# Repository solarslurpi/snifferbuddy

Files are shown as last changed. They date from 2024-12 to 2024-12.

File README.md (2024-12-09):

(snifferbuddy_doc)=
# SnifferBuddy
## About
SnifferBuddy, a puck-shaped device, measures ambient conditions—temperature, humidity, CO2, and light status—in the grow tent using an SCD4x sensor and a photoresistor. It calculates VPD and publishes the data via MQTT.

This guide details the process of assembling SnifferBuddy, configuring its software, and understanding its operation.  

SnifferBuddy broadcasts MQTT messages packed with SCD-4x sensor data. Node-red, home assistant, and any software tuned to SnifferBuddy's MQTT topic can pick up and utilize this data. 

## Glossary
- **MQTT (Message Queuing Telemetry Transport)**: A lightweight messaging protocol used for sending and receiving telemetry data in the form of messages between devices, servers, and applications. MQTT is especially useful in scenarios where network bandwidth is at a premium.
- **SCD-4x**: This refers to a series of CO2 sensors from Sensirion, specifically the SCD-40 and SCD-41 models. These sensors are integrated into breakout boards developed and sold by Adafruit. The breakout boards make it easier to interface with and use the sensors in projects. The Adafruit product pages for the [SCD-40](https://www.adafruit.com/product/5187) and [SCD-41](https://www.adafruit.com/product/5190) provide further details. SnifferBuddy uses this breakout board.
- **STEMMA Connector**: STEMMA is a standard adopted by Adafruit to make connecting sensors and devices easier, eliminating the need for soldering. It uses JST connectors, specifically JST PH for larger, power-focused connections and JST SH for smaller, data-focused connections. STEMMA connectors means connections don't require soldering or breadboarding {material-regular}`celebration;1em;sd-text-blue`.
- **QT Py ESP32-S2**: Adafruit's compact microcontroller, featuring an ESP32-S2 chip with built-in USB and Wi-Fi capabilities. It supports easy, solder-free connections to devices via a built-in STEMMA QT connector. More on [the product page](https://www.adafruit.com/product/5187).
- **CircuitPython**: An open-source derivative of MicroPython developed and maintained by Adafruit. The design intent is to simplify experimenting and learning to code on low-cost microcontroller boards. More on [the product page](https://circuitpython.org/)
(make_snifferbuddy)=
## Make SnifferBuddy
### 1. Get the parts together

The hardware needed to build SnifferBuddy includes:

| Component | Cost | Reason |
|---|---|---|
| [QT Py ESP32-S2](https://www.adafruit.com/product/5325) | $12.50 | Excellent quality.  Easy to use with CircuitPython and WiFi. STEMMA connector makes it easy to connect the SCD-40 or 41.  Small size.
| [USB-C DATA Cable](https://amzn.to/3OW5SdE) | $10 | Includes wires for data transfer.  There are probably more inexpensive cables.  Please make sure to use one with data wires.
| [SCD-40 BoB](https://www.adafruit.com/product/5187) | $44.95 | Excellent quality.  Provides accurate CO2 readings.  STEMMA connector makes it easy to connect to the QT PY.
| [JST SH 4-Pin Cable](https://www.adafruit.com/product/4399) | $0.95 | Excellent quality. Connects the QT PY to the SCD-4x. No soldering required.
| Photoresistor | pennies | At some point I bought [a pack of photoresistors on Amazon](https://www.amazon.com/s?k=photoresistor).
| 12K  Resistor | pennies | As with photoresistors, I bought [a pack of resistors on Amazon](https://www.amazon.com/s?k=resistor).
| wiring | pennies | I like to use [silicone wires like this wire kit on Amazon](https://amzn.to/3C6chLU).
| enclosure | pennies | The design is an evolution of the wonderful [Tiny-D1 modular case for Wemos D1 mini by sumpfing](https://www.thingiverse.com/thing:4084654).  Thank you!

### 2. Print out the Enclosure
```{figure} images/snifferbuddy_on_printbed.jpg
:align: center
:height: 350

Top and Bottom Rings of the SnifferBuddy enclosure.
```

Print out these files on your 3D printer:
- Top Ring: Print out [scd40-ring.3mf](../enclosures/SnifferBuddy/scd-40/scd40-ring.3mf).
- Bottom Ring: Print out [bottom_qtpy.3mf](../enclosures/SnifferBuddy/scd-40/bottom_qtpy.3mf).

(_connect_wires)=
### 3. Connect Wires
- Connect the photoresistor wiring.  This requires a bit of soldering.
```{figure} images/SnifferBuddy_photoresistor_wiring.png
:align: center
:height: 350

Diagram of Photoresistor Wiring
```
```{figure} images/snifferbuddy_photoresistor_wiring_real.jpg
:align: center
:height: 350

QT Py wired with the Photoresistor circuit.
```
Use A2 as the pin to read for the photoresistor.
- Connect the QT Py and the SCD40.
```{figure} images/snifferbuddy_connected_scd4x.jpeg
:align: center
:height: 350

QT Py connected to scd4x sensor using Adafruit's STEMMA QT
```
### 4. Install CircuitPython onto the QT Py

Follow [Adafruit's instructions](https://learn.adafruit.com/adafruit-qt-py-esp32-s2/circuitpython).

```{note}
The CircuitPython version tested for compatibility with SnifferBuddy was 8.1.0.
```

### 5. Download Files To CircuitPython's Root Dir
{material-regular}`celebration;1em;sd-text-blue`  It is so wonderfully amazing that we can just drag and drop files onto our QT Py {material-regular}`celebration;1em;sd-text-blue`

Download these two files to the CIRCUITPY drive:

{material-regular}`download;1em;sd-text-success` [code.py](../growbuddiesproject/growbuddies/CircuitPython/src/code.py)
   - contains all of SnifferBuddy's code.  The code is [discussed later](_code_doc).

{material-regular}`download;1em;sd-text-success` [conf.json](../growbuddiesproject/growbuddies/CircuitPython/src/config.json)
   - contains all the values that can be changed.  The contents of the config file is discussed below.
### 6. Edit then Save the config file
The contents of the config file are listed below.  At a minimum, the wifi ssid and password must be set.

```{eval-rst}
.. literalinclude:: ../growbuddiesproject/growbuddies/CircuitPython/src/config.json

```
- **name and version**: The 'name' field distinguishes each SnifferBuddy when multiple units are used. The 'version' field indicates the code version running on each SnifferBuddy's QT Py microcontroller, ensuring accurate tracking of software updates.
- **wifi ssid and password**:  **Before deploying SnifferBuddy, it's essential to update these values** to align with your home network's WiFi settings.
- **mqtt broker and port**: Use any MQTT broker.  By default, the MQTT broker is Gus.  The default MQTT port is 1883.
- **temperature_unit**: The value is either an "F" or a "C", depending if readings should be stored in Fahrenheit or in Celsius.
- **sensor_type**: Supported types include scd40 and scd41.
- **light_threshold**: It is essential to know whether the grow light is on or off. SnifferBuddy uses the Photoresistor as a means to determine the relative light level.  As shown in the diagram within the [wiring section](_connect_wires), the light level is read from an analog pin on the QT Py.  The Photoresistor is the bottom resistor in the Voltage Divider circuit.  This means the more light, the higher the reading will be for the light level.  When code.py is run from Mu, print statements will show the light reading as shown below:

```
Published: {"scd41": {"vpd": 1.43, "temperature": 78.314, "name": "sunshine", "light": "OFF", "co2": 929, "humidity": 45.5017, "unit": "F", "version": 0.1}}
light reading: 45735
```
In this case, the reading is 45,735.  You may want to experiment to find the "ideal" threshold value for your setup.  It turned out 51000 was the ideal value for mine.
- **log_topic**: The MQTT topic used by the logging handler to send log messages to the MQTT broker.
- **lwt_topic**: Used along with **offline_payload** to set the Last Will and Testament. The **online_payload** is sent to the **lwt_topic** upon receiving a callback from the MQTT Broker that SnifferBuddy has connected.
```
    mqtt_client.will_set(config["lwt_topic"], config["offline_payload"], retain=True)
```
- **payload_topic**: The topic used to send the light info and scd4x readings.
### 7. Download Library Files to the lib Directory
Create the lib directory on your CIRCUITPY drive.
#### a. Download to the CIRCUITPY/lib directory:
{material-regular}`download;1em;sd-text-success` [log_mqtt.py](../growbuddiesproject/growbuddies/CircuitPython/src/log_mqtt.py)
#### b. Download the CircuitPython Libraries
Based on the version of CircuitPython you installed on the QT Py, download the [corresponding CircuitPython Libraries](https://circuitpython.org/libraries).
#### c. Copy Libraries to the CIRCUITPY/lib directory:
The following libraries need to be copied to CIRCUITPY/lib:
- adafruit_minimqtt
- adafruit_logging.mpy
- adafruit_scd4x.mpy
### 8. Plug In Your SnifferBuddy
At this point, we're hoping everything "just works"!  Plug in your SnifferBuddy to a 5V USB port.  If SnifferBuddy is working, there will be entries in the MQTT broker.
## Accuracy - SCD4x
Section 1 of the [SCD4x datasheet](https://sensirion.com/media/documents/48C4B7FB/6426E14D/CD_DS_SCD40_SCD41_Datasheet_D1_052023.pdf) describes the lower and upper bounds that a CO2, relative humidity, or temperature reading will range based on the SCD4x's accuracy.  A python program, `calculate_scd40_bounds.py`, calculates these offsets given a value for the SCD40.  For example, if the temperature reads 70 degrees F, the actual value can range from 68.6 to 71.4 degrees based on the accuracy.

## Adjusting Temperature and Relative Humidity Readings - SCD4x

### On-Chip Signal Compensation
A temperature offset is utilized to fine-tune the sensor's temperature and relative humidity (RH) output signals. The correlation between temperature and humidity necessitates an accurate temperature reading for a precise RH reading, given that moisture-carrying capacity of air is temperature-dependent. The [SCD4x datasheet](https://sensirion.com/media/documents/48C4B7FB/6426E14D/CD_DS_SCD40_SCD41_Datasheet_D1_052023.pdf) discusses the On-Chip Output Signal Compensation in section 3.6.  It's the way the chip compensates for temperature readings skewed due to self-heating from the sensor and nearby electronics, while also taking into account other influences like ambient temperature variations and airflow disruptions.   Initially, the temperature offset is set to 4°C to mitigate self-generated heat, with adjustable values between 0°C and 20°C to accommodate other environmental factors. Although a negative offset could technically be used if the sensor reads too cold, it's outside the recommended range.
### Adjusting temperature readings
1. Determine if a temperature offset is needed by placing an external reference temperature sensor with snifferbuddy and determine if after 24 hours.
2. If the reading is significantly outside the bounds, consider changing the temperature offset.
3. Place the SnifferBuddy and a reference temperature sensor at the place in the grow tent you wish to have SnifferBuddy hanging around. Wait 24 hours so both sensor aclimate.
## Adjusting Light ON/OFF threshold
A simple photoresistor is used to determine whether the light is on or off. CircuitPython maps photoresistor readings to values between 0 and 65535.  By default, light on happens when the photoresistor value is > 45,000.  This can be adjusted.
1. Put SnifferBuddy where you want to hang it.
2. Turn the light on. If SnifferBuddy sends readings that says the light is on, you are done.
3. If SnifferBuddy says the light is off when it is on, send a calibrate light mqtt message.  By doing so, SnifferBuddy will adjust it's light threshold.

## Debug
Sadly, it is a rare moment when something works the first time. Take a deep breath and let's get started!
### Check the Print Statements
In this scenario, the QT Py is plugged into a USB on your PC/Mac.  You have installed the [Mu editor](https://codewith.mu/), and can load and run code.py.  There are print statements that should help you determine what the problem might be.
### Check Out the MQTT Broker
Have any messages been sent?  The easiest way to check is to use a tool like [mqtt Explorer](http://mqtt-explorer.com/).  This tool does exactly what the name implies.  It allows you to explore the mqtt traffic as it whizzes by.  You can also publish messages.  Very handy.
```{figure} images/mqtt_explorer.jpg
:align: center
:height: 350

SnifferBuddy Topics on the Gus MQTT Broker
```
The first messages sent include:
1. A message to the lwt topic letting everyone know a SnifferBuddy is connected to the MQTT broker.

```
    client.publish(userdata["lwt_topic"], userdata["online_payload"], retain=True)
```
Check the configuration file for what the actual "online_payload" message is.

2. A log message sent before readings are published.

```
logger.debug("Sending Readings")
```
The logging message with be under the config['log_topic'] (default is SnifferBuddy/log).  It will look like this:
```
8.000: DEBUG - Sending Readings
```
Where:
- 8.000 is a floating point number that represents the number of seconds since boot (see [monotonic time](https://learn.adafruit.com/clue-sensor-plotter-circuitpython/time-in-circuitpython )).
- DEBUG notes this logging message to be at the debug level.
- "Sending Readings" is the message.

### Using LWT and Logging for Debugging

SnifferBuddy has set up the optional Last Will and Testament (LWT) feature of MQTT. LWT is a method to notify clients by the broker when the client ungracefully disconnects or stops sending messages.  To set up LWT, the will_set() method is called:
```
mqtt_client.will_set(config["lwt_topic"], config["offline_payload"], retain=True)
```
prior to connecting.  This sets the topic and the text for the payload of the broadcasted message when the broker detects the client is offline.

### HELP!
If you need help debugging or have other questions, please send a message.
```{button-link} https://github.com/solarslurpi/GrowBuddies/discussions
:outline:
:color: success

 {octicon}`comment;1em;sd-text-success` Comments & Questions
```
(_code_doc)=
## Code Documentation
Starting at the `main()` function:
```{eval-rst}
.. automodule:: growbuddies.CircuitPython.src.code
   :members: main

```
on:: growbuddies.CircuitPython.src.code.process_light_info
```

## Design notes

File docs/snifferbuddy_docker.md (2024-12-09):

# SnifferBuddy Docker Quick Start Guide

## Building the Image
To build the Docker image for the SnifferBuddy application, run the following command in the directory containing the Dockerfile:

```bash
docker build -t snifferbuddy:0.0.1 -t snifferbuddy:latest .
```
- **`docker build`**: This is the command to build a Docker image.
- **`-t`**: This flag is used to tag the image with a name and optionally a version. You can use multiple `-t` flags to assign multiple tags to the same image.
    - **`snifferbuddy:0.0.1`**: This is the first tag for the image. It includes the version tag. This is useful for version control and helps in identifying different builds of the same image.
    - **`snifferbuddy:latest`**: This is the second tag for the image. It uses the same image name but with the `latest` tag. The `latest` tag is a convention used to indicate the most recent or stable version of an image. It is not automatically updated and must be explicitly set.
- **`.`**: This is the build context, which is the directory where the Dockerfile is located. The `.` indicates the current directory. Docker will use this directory to find the Dockerfile and any files it needs to include in the image.

## Running the Container
To run the container with automatic restart enabled, use the following command:

```bash
docker run -d \
    --name snifferbuddy \
    --restart unless-stopped \
    snifferbuddy:latest
```

- **`docker run`**: This is the command to create and start a new container from a specified Docker image.
- **`-d`**: This flag runs the container in detached mode, meaning it runs in the background. This is useful for running services or applications that do not require direct interaction.
- **`--name snifferbuddy`**: This option assigns a name to the container. Naming containers makes it easier to manage them, as you can refer to them by name instead of their container ID. e.g.: `docker logs snifferbuddy`.
- **`--restart unless-stopped`**: This flag sets the container's restart policy. The `unless-stopped` policy means the container will automatically restart if it stops or if the Docker daemon restarts, except if it was manually stopped. This is useful for ensuring high availability and resilience of services across reboots and Docker daemon restarts.
- **`snifferbuddy:latest`**: This is the name and tag of the Docker image from which the container is created. It specifies which image to use for the container. 

## Managing the Container
Here are some useful commands for managing the Docker container:

```bash
# Stop the container
docker stop sensor-monitor

# Start a stopped container
docker start sensor-monitor

# View logs
docker logs -f sensor-monitor

# Remove container (if needed)
docker rm sensor-monitor
```

## Important Notes

### Automatic Restart
- The container is configured with `--restart unless-stopped`
- It will automatically restart after:
  - System reboots
  - Docker daemon restarts
  - Container crashes
- It will NOT restart if manually stopped with `docker stop`

### Configuration
- Application configuration is in `config.yaml`
- Modify this file before building the image
- If you need to change configuration:
  1. Update `config.yaml`
  2. Rebuild the image
  3. Stop and remove the old container
  4. Start a new container

### Troubleshooting
1. Check container status:
   ```bash
   docker ps -a
   ```

2. View logs:
   ```bash
   docker logs -f sensor-monitor
   ```

3. Access container shell (if needed):
   ```bash
   docker exec -it sensor-monitor /bin/bash
   ```

### Development Workflow
1. Make code changes
2. Rebuild image:
   ```bash
   docker build -t sensor-monitor .
   ```
3. Restart container:
   ```bash
   docker stop sensor-monitor
   docker rm sensor-monitor
   docker run -d --name sensor-monitor --restart unless-stopped sensor-monitor
   ```

## Requirements
- Docker installed on Raspberry Pi
- Network access for MQTT connections
- Sufficient disk space for logs and data storage

## Security Notes
- Container runs as non-root user 'appuser'
- Source code is copied into container during build
- Configuration is baked into the image

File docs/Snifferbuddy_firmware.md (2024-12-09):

# SnifferBuddy Puck Firmware
The firmware is [Tasmota](https://tasmota.github.io/docs/), a popular open-source firmware for ESP8266/ESP32 devices. Tasmota provides:
- A robust web interface for configuration.
- Built-in MQTT support.
- Over-the-air (OTA) updates.
- Support for a variety of Sensors.
- Support to add drivers for additional sensors.
- Automatic reconnection handling for both WiFi and MQTT.
## Installation
Installation assumes you have a [SnifferBuddy Puck](snifferbuddy_puck.md).
- Before you begin, make sure:
    - you have a USB data cable.  Cheaper USB cables do not support data transfer.
    - your OS has a CH340/CH341 driver installed.  I run on Windows 10 and use the CH340 driver. [This documentation gives install info for Windows, Mac, and Linux](https://sparks.gogo.co.nz/ch340.html).

## Customizing the Tasmota build
Not all sensor drivers can be installed on the ESP2866 at the same time.  The SCD4X sensor driver is one of the drivers that is not installed by default.  A custom build is needed to add the SCD4X driver.
### Compiling in the SCD4X Driver

[Compile your build](https://tasmota.github.io/docs/Compile-your-build/) provides the documentation on how to compile a custom build.  Choose the `Gitpod` method.  It is a very simple and fast way to get started.  Follow the guide up and through compiling the firmware.

When done, the firmware files are in the folder `/Tasmota/build_output/firmware/`.

Download the `.bin` file.

Navigate to [the Tasmota Install URL](https://tasmota.github.io/install/). Look towards the bottom of the page to upload the `.bin` file.  The button say `Upload factory.bin`.  This is where you upload the `.bin` file you just downloaded. 

Install the firmware. Once the install is successful, the UI will navigate through entering wifi credentials.  The final UI has a button to `Visit Device`. Click this button to open the device's interface. 

Go the the `Console` and type `i2cdriver`.  The `SCD4X` driver's i2c address is `62`.

## Accessing the UI
- Connect to your network and locate your SnifferBuddy's IP address. I use the AngryIP Scanner tool for this.
- Once you find the IP address, enter it in a web browser

The main page displays current sensor readings and device status.
<figure style="text-align: center; margin: auto;">
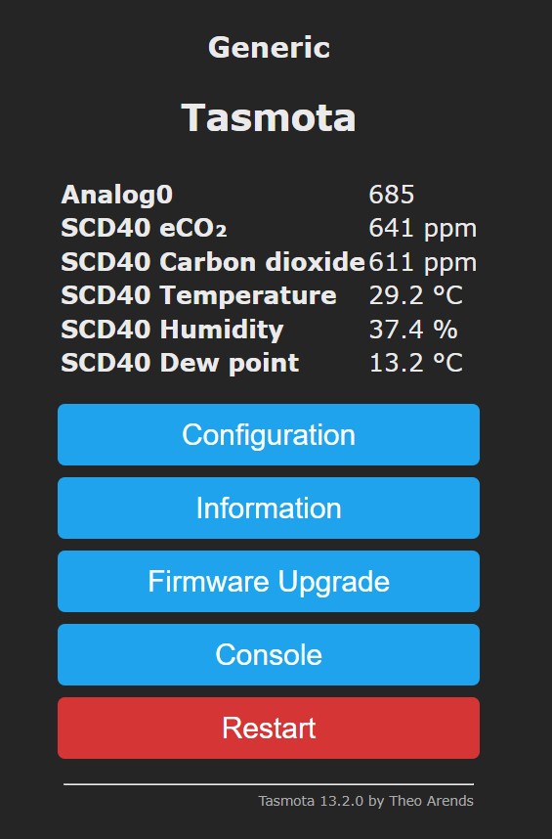
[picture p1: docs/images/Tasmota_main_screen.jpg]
Image of Tasmota's main screen showing SCD40 readings.
    
    <figcaption style="text-align: center">Tasmota main screen showing SCD40 readings</figcaption>
</figure>

## Configuration Settings

The configuration for the Sensor Monitoring System is managed through a combination of a Python module (`config.py`) and a YAML file (`config.yaml`). This setup allows for flexible and easy-to-manage configuration settings that can be adjusted without modifying the application code.

### Configuration Files

1. **`config.py`**: This Python module defines the structure and default values for the application's configuration using Pydantic, a data validation and settings management library. It provides a programmatic way to load and validate configuration data, ensuring that all required fields are present and correctly typed.

2. **`config.yaml`**: This YAML file contains the actual configuration settings for the application. It is designed to be user-editable, allowing you to customize the application's behavior by changing the values in this file. If the file is not present, the application will fall back to default settings defined in `config.py`.

### Configuration Properties

The configuration is divided into two main sections:

#### MQTT Configuration

- **`host`**: The hostname or IP address of the MQTT broker. This is where the application will connect to receive sensor data. Default is `"localhost"`.
- **`port`**: The port number on which the MQTT broker is listening. The default port for MQTT is `1883`.
- **`topic_prefix`**: The prefix for MQTT topics that the application will subscribe to. This allows the application to filter messages based on topic hierarchy. Default is `"sensors/#"`, which subscribes to all topics under `sensors`.
#### Database Configuration
- **`database_path`**: The file path to the SQLite database where sensor readings will be stored. This path can be absolute or relative, and it defaults to a hidden directory in the user's home folder: `"~/.sensor_monitor/readings.db"`.
### How to Use
1. **Edit `config.yaml`**: Open the `config.yaml` file in a text editor and modify the values as needed to match your environment and requirements.

## Docker

```
docker build -t solarslurpie/snifferbuddy:latest .
```

```bash
docker run -v $(pwd)/config.yaml:/usr/app/config.yaml --name snifferbuddy -d  --restart always solarslurpie/snifferbuddy:latest
```

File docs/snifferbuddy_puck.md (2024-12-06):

(snifferbuddy_doc)=
# SnifferBuddy Puck

## About
The SnifferBuddy Puck measures ambient conditions—temperature, humidity, CO2, and light status—in the grow tent using an SCD4x sensor and a photoresistor.

<figure style="text-align: center; margin: auto;">
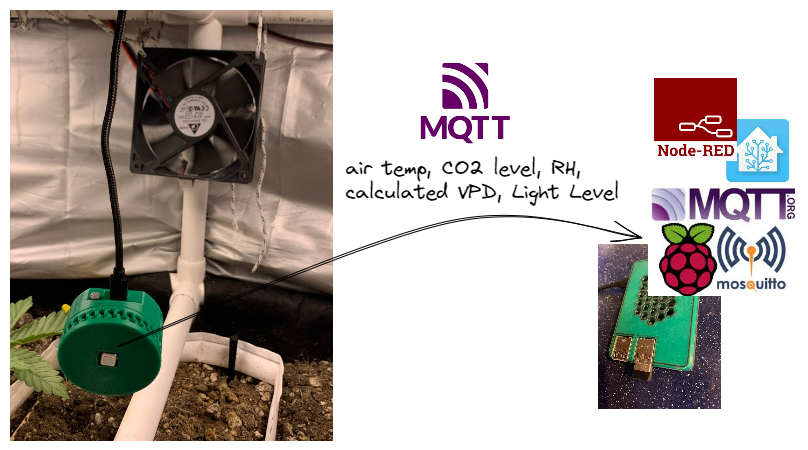
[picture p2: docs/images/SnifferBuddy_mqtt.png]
Diagram showing SnifferBuddy's MQTT communication architecture
    
    <figcaption style="text-align: center">SnifferBuddy calculates VPD and publishes the data via MQTT</figcaption>
</figure>
SnifferBuddy sends its readings over MQTT. Using MQTT means the readings can be integrated into other apps such as Node-RED and Home Assistant.  For this project, SnifferBuddy is integrated into GrowBuddies.ai.

## Hardware

### 1. Get the parts together

The hardware needed to build SnifferBuddy includes:

Materials
---------

- `SCD30 sensor <https://www.adafruit.com/product/4867>`_ component.
- `ESP8286 <https://www.aliexpress.us/item/2251832645039000.html>`_ component.
- Photoresistor and 10K through hole resistor component.
- Print out the `case top <https://github.com/solarslurpi/GrowBuddy/blob/main/enclosures/SnifferBuddy/base%20and%20lid%20v14.f3d>`_.
- print out the SCD30 enclosure `(case bottom) <https://github.com/solarslurpi/GrowBuddy/blob/main/enclosures/SnifferBuddy/scd30%20enclosure%20v1.f3d>`_.
- USB chord to plug the ESP8286 to power.
- USB power hub to plug the USB chord into the wall.

| Component | Cost | Reason |
|---|---|---|
| Enclosure | pennies | The design is an evolution of the wonderful [Tiny-D1 modular case for Wemos D1 mini by sumpfing](https://www.thingiverse.com/thing:4084654).
| Wemos D1 mini | $2 | Works well with Tasmota.
| Cable to PC | $5-$9  | if the Wemos version is 3 or earlier, the cable is the micro-B USB. Wemos 4 and later use USB-C.
| [SCD-40 or 41 BoB](https://www.adafruit.com/product/5187) | $44.95 | Excellent quality.  Provides accurate CO2 readings.  STEMMA connector makes it easy to connect to the QT PY.
| [JST SH 4-Pin Cable](https://www.adafruit.com/product/4399) | $0.95 | Excellent quality. Connects the QT PY to the SCD-4x. No soldering required.
| Photoresistor | pennies | At some point I bought [a pack of photoresistors on Amazon](https://www.amazon.com/s?k=photoresistor).
| 12K  Resistor | pennies | As with photoresistors, I bought [a pack of resistors on Amazon](https://www.amazon.com/s?k=resistor).
| wiring | pennies | I like to use [silicone wires like this wire kit on Amazon](https://amzn.to/3C6chLU).
| enclosure | pennies | The design is an evolution of the wonderful [Tiny-D1 modular case for Wemos D1 mini by sumpfing](https://www.thingiverse.com/thing:4084654).  Thank you!

### 2. Print out the Enclosure

Print out these files on your 3D printer:
- Print out [the top ring](../enclosure/SCD4X/scd40-ring.3mf).
- Print out [the bottom ring](../enclosure/SCD4X/bottom_qtpy.3mf).

<figure style="text-align: center; margin: auto;">
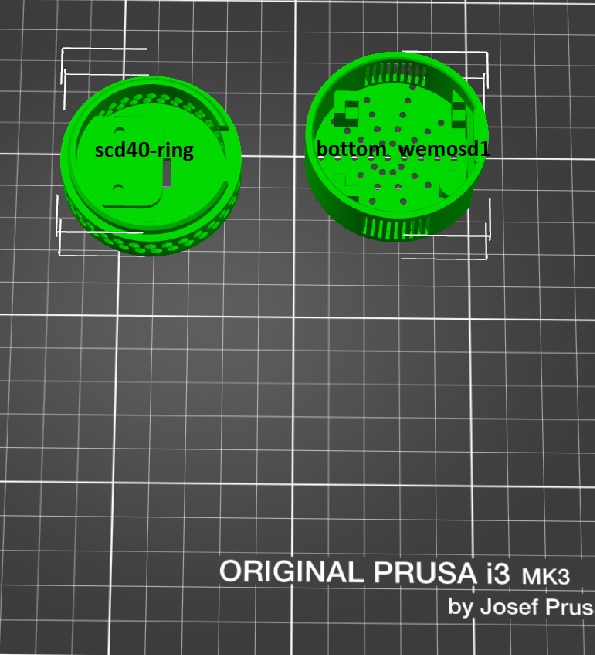
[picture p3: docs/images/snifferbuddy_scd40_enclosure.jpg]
SnifferBuddy's Enclosure
    
    <figcaption style="text-align: center">SnifferBuddy's Enclosure</figcaption>
</figure>

### 3. Connect Wires
- Connect the photoresistor wiring.  This requires a bit of soldering.
```{figure} images/SnifferBuddy_photoresistor_wiring.png
:align: center
:height: 350

Diagram of Photoresistor Wiring
```
```{figure} images/snifferbuddy_photoresistor_wiring_real.jpg
:align: center
:height: 350

QT Py wired with the Photoresistor circuit.
```
Use A2 as the pin to read for the photoresistor.
- Connect the QT Py and the SCD40.
```{figure} images/snifferbuddy_connected_scd4x.jpeg
:align: center
:height: 350

QT Py connected to scd4x sensor using Adafruit's STEMMA QT
```
### 4. Install CircuitPython onto the QT Py

Follow [Adafruit's instructions](https://learn.adafruit.com/adafruit-qt-py-esp32-s2/circuitpython).

```{note}
The CircuitPython version tested for compatibility with SnifferBuddy was 8.1.0.
```

### 5. Download Files To CircuitPython's Root Dir
{material-regular}`celebration;1em;sd-text-blue`  It is so wonderfully amazing that we can just drag and drop files onto our QT Py {material-regular}`celebration;1em;sd-text-blue`

Download these two files to the CIRCUITPY drive:

{material-regular}`download;1em;sd-text-success` [code.py](../growbuddiesproject/growbuddies/CircuitPython/src/code.py)
   - contains all of SnifferBuddy's code.  The code is [discussed later](_code_doc).

{material-regular}`download;1em;sd-text-success` [conf.json](../growbuddiesproject/growbuddies/CircuitPython/src/config.json)
   - contains all the values that can be changed.  The contents of the config file is discussed below.
### 6. Edit then Save the config file
The contents of the config file are listed below.  At a minimum, the wifi ssid and password must be set.

```{eval-rst}
.. literalinclude:: ../growbuddiesproject/growbuddies/CircuitPython/src/config.json

```
- **name and version**: The 'name' field distinguishes each SnifferBuddy when multiple units are used. The 'version' field indicates the code version running on each SnifferBuddy's QT Py microcontroller, ensuring accurate tracking of software updates.
- **wifi ssid and password**:  **Before deploying SnifferBuddy, it's essential to update these values** to align with your home network's WiFi settings.
- **mqtt broker and port**: Use any MQTT broker.  By default, the MQTT broker is Gus.  The default MQTT port is 1883.
- **temperature_unit**: The value is either an "F" or a "C", depending if readings should be stored in Fahrenheit or in Celsius.
- **sensor_type**: Supported types include scd40 and scd41.
- **light_threshold**: It is essential to know whether the grow light is on or off. SnifferBuddy uses the Photoresistor as a means to determine the relative light level.  As shown in the diagram within the [wiring section](_connect_wires), the light level is read from an analog pin on the QT Py.  The Photoresistor is the bottom resistor in the Voltage Divider circuit.  This means the more light, the higher the reading will be for the light level.  When code.py is run from Mu, print statements will show the light reading as shown below:

```
Published: {"scd41": {"vpd": 1.43, "temperature": 78.314, "name": "sunshine", "light": "OFF", "co2": 929, "humidity": 45.5017, "unit": "F", "version": 0.1}}
light reading: 45735
```
In this case, the reading is 45,735.  You may want to experiment to find the "ideal" threshold value for your setup.  It turned out 51000 was the ideal value for mine.
- **log_topic**: The MQTT topic used by the logging handler to send log messages to the MQTT broker.
- **lwt_topic**: Used along with **offline_payload** to set the Last Will and Testament. The **online_payload** is sent to the **lwt_topic** upon receiving a callback from the MQTT Broker that SnifferBuddy has connected.
```
    mqtt_client.will_set(config["lwt_topic"], config["offline_payload"], retain=True)
```
- **payload_topic**: The topic used to send the light info and scd4x readings.
### 7. Download Library Files to the lib Directory
Create the lib directory on your CIRCUITPY drive.
#### a. Download to the CIRCUITPY/lib directory:
{material-regular}`download;1em;sd-text-success` [log_mqtt.py](../growbuddiesproject/growbuddies/CircuitPython/src/log_mqtt.py)
#### b. Download the CircuitPython Libraries
Based on the version of CircuitPython you installed on the QT Py, download the [corresponding CircuitPython Libraries](https://circuitpython.org/libraries).
#### c. Copy Libraries to the CIRCUITPY/lib directory:
The following libraries need to be copied to CIRCUITPY/lib:
- adafruit_minimqtt
- adafruit_logging.mpy
- adafruit_scd4x.mpy
### 8. Plug In Your SnifferBuddy
At this point, we're hoping everything "just works"!  Plug in your SnifferBuddy to a 5V USB port.  If SnifferBuddy is working, there will be entries in the MQTT broker.
## Accuracy - SCD4x
Section 1 of the [SCD4x datasheet](https://sensirion.com/media/documents/48C4B7FB/6426E14D/CD_DS_SCD40_SCD41_Datasheet_D1_052023.pdf) describes the lower and upper bounds that a CO2, relative humidity, or temperature reading will range based on the SCD4x's accuracy.  A python program, `calculate_scd40_bounds.py`, calculates these offsets given a value for the SCD40.  For example, if the temperature reads 70 degrees F, the actual value can range from 68.6 to 71.4 degrees based on the accuracy.

## Adjusting Temperature and Relative Humidity Readings - SCD4x

### On-Chip Signal Compensation
A temperature offset is utilized to fine-tune the sensor's temperature and relative humidity (RH) output signals. The correlation between temperature and humidity necessitates an accurate temperature reading for a precise RH reading, given that moisture-carrying capacity of air is temperature-dependent. The [SCD4x datasheet](https://sensirion.com/media/documents/48C4B7FB/6426E14D/CD_DS_SCD40_SCD41_Datasheet_D1_052023.pdf) discusses the On-Chip Output Signal Compensation in section 3.6.  It's the way the chip compensates for temperature readings skewed due to self-heating from the sensor and nearby electronics, while also taking into account other influences like ambient temperature variations and airflow disruptions.   Initially, the temperature offset is set to 4°C to mitigate self-generated heat, with adjustable values between 0°C and 20°C to accommodate other environmental factors. Although a negative offset could technically be used if the sensor reads too cold, it's outside the recommended range.
### Adjusting temperature readings
1. Determine if a temperature offset is needed by placing an external reference temperature sensor with snifferbuddy and determine if after 24 hours.
2. If the reading is significantly outside the bounds, consider changing the temperature offset.
3. Place the SnifferBuddy and a reference temperature sensor at the place in the grow tent you wish to have SnifferBuddy hanging around. Wait 24 hours so both sensor aclimate.
## Adjusting Light ON/OFF threshold
A simple photoresistor is used to determine whether the light is on or off. CircuitPython maps photoresistor readings to values between 0 and 65535.  By default, light on happens when the photoresistor value is > 45,000.  This can be adjusted.
1. Put SnifferBuddy where you want to hang it.
2. Turn the light on. If SnifferBuddy sends readings that says the light is on, you are done.
3. If SnifferBuddy says the light is off when it is on, send a calibrate light mqtt message.  By doing so, SnifferBuddy will adjust it's light threshold.

## Debug
Sadly, it is a rare moment when something works the first time. Take a deep breath and let's get started!
### Check the Print Statements
In this scenario, the QT Py is plugged into a USB on your PC/Mac.  You have installed the [Mu editor](https://codewith.mu/), and can load and run code.py.  There are print statements that should help you determine what the problem might be.
### Check Out the MQTT Broker
Have any messages been sent?  The easiest way to check is to use a tool like [mqtt Explorer](http://mqtt-explorer.com/).  This tool does exactly what the name implies.  It allows you to explore the mqtt traffic as it whizzes by.  You can also publish messages.  Very handy.
```{figure} images/mqtt_explorer.jpg
:align: center
:height: 350

SnifferBuddy Topics on the Gus MQTT Broker
```
The first messages sent include:
1. A message to the lwt topic letting everyone know a SnifferBuddy is connected to the MQTT broker.

```
    client.publish(userdata["lwt_topic"], userdata["online_payload"], retain=True)
```
Check the configuration file for what the actual "online_payload" message is.

2. A log message sent before readings are published.

```
logger.debug("Sending Readings")
```
The logging message with be under the config['log_topic'] (default is SnifferBuddy/log).  It will look like this:
```
8.000: DEBUG - Sending Readings
```
Where:
- 8.000 is a floating point number that represents the number of seconds since boot (see [monotonic time](https://learn.adafruit.com/clue-sensor-plotter-circuitpython/time-in-circuitpython )).
- DEBUG notes this logging message to be at the debug level.
- "Sending Readings" is the message.

### Using LWT and Logging for Debugging

SnifferBuddy has set up the optional Last Will and Testament (LWT) feature of MQTT. LWT is a method to notify clients by the broker when the client ungracefully disconnects or stops sending messages.  To set up LWT, the will_set() method is called:
```
mqtt_client.will_set(config["lwt_topic"], config["offline_payload"], retain=True)
```
prior to connecting.  This sets the topic and the text for the payload of the broadcasted message when the broker detects the client is offline.

### HELP!
If you need help debugging or have other questions, please send a message.
```{button-link} https://github.com/solarslurpi/GrowBuddies/discussions
:outline:
:color: success

 {octicon}`comment;1em;sd-text-success` Comments & Questions
```
(_code_doc)=
## Code Documentation
Starting at the `main()` function:
```{eval-rst}
.. automodule:: growbuddies.CircuitPython.src.code
   :members: main

```

```{eval-rst}
.. autofunction:: growbuddies.CircuitPython.src.code.load_config
.. autofunction:: growbuddies.CircuitPython.src.code.connect_wifi
.. autofunction:: growbuddies.CircuitPython.src.code.connect_mqtt
.. autofunction:: growbuddies.CircuitPython.src.code.read_and_mqtt_scd4x_data
.. autofunction:: growbuddies.CircuitPython.src.code.process_light_info
```

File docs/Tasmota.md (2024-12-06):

## Enabling/Disabling Features
An example of this is enabling suport for the `SCD40` sensor.  By default, the Tasmota firmware does not include the `SCD40` driver in the build. To enable it, the easiest way is to follow the instructions:
- [The YouTube video _Compiling your own custom Tasmota on the web - No installs, no coding!_](https://www.youtube.com/watch?v=vod3Woj_vrs)
- [The Tasmota documentation covering compiling with Gitpod](https://tasmota.github.io/docs/Compile-your-build/)

Once the editor is loaded, open up the file `tasmota/my_user_config.h`. Uncomment out the `define` line for the `SCD40` sensor. 

_Note:_ There are sensors that are loaded taking up memory that are not used. I comment out some of these to save memory. However, I do this somewhat randomly.  In the future, I will add a tool to help with this.

Then follow the steps in

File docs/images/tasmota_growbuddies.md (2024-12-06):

# Tasmota

This documentation needs to be updated. The project evolved from being all about Tasmota to using Tasmotized plugs (because of mqtt).  One thing that needs to be added is sometimes the mqtt messages can fail to reach the power plugs. The problems with this is turning off either the humidifier or CO2 solenoid. One thing we do is to set a timeout
(_install_mistbuddy_smartplugs)=
## Installing on the Sonoff Smart Plugs
These directions assumed you have two [Sonoff S31 plugs](https://amzn.to/3xnPWYc) smart plugs.

### 1. Flash The Smart Plugs
We need a way to turn a plug on or off using MQTT messaging.  Tasmotized plugs can do this.

The Sonoff S31 (or S31 Lite) can be flashed so that Tasmota is running on our local network. [This YouTube video gives instructions on how to flash Tosmota](https://www.youtube.com/watch?v=9N58uy3ezvA).

ooh! Extra care when soldering.  If not, well...it is way too easy to rip off one of the pads...

Once flashed:
1. Put the plug back together.
2. Plug the smart plug into a wall socket.
3. Connect to the smart plug from your PC/Mac.
You can use a tool like [Angry IP](https://angryip.org/) to show the IP address.
:::{figure} images/angry_ip_tasmota.jpg
:align: center
:scale: 70

Angry IP Scan Shows Tasmota
:::

 Set the Module type to Sonoff S31.

:::{figure} images/Tasmota_S31_Config.jpg
:align: center
:scale: 80

Tasmota Sonoff Configuration
:::
Use the Tasmota S31 configuration when you go through the [Tasmota install](tasmota_installation)

| Installing | Follow Steps with these icons  |
| :--- | ---: |
| SnifferBuddy | {octicon}`sun;1em;sd-text-success`, {octicon}`north-star;1em;sd-text-success`|
| Smart Plugs for MistBuddy | {octicon}`plug;1em;sd-text-success`, {octicon}`north-star;1em;sd-text-success`|
| SnapBuddy | {octicon}`device-camera;1em;sd-text-success`, {octicon}`north-star;1em;sd-text-success`|

[Tasmota](https://tasmota.github.io/docs/) has enabled us to build low-cost sensor and camera devices that primarily use MQTT to transmit sensor readings.  To date, GrowBuddies have implemented two ESP hardware configurations: the Wemos D1 ESP286 for sensor functionality and the ESP32-AI Thinker Cam for capturing time-lapse and streaming video.
## Resources
[Wi-Fi module pinouts](https://tasmota.github.io/docs/Pinouts/#psf-b85psf-b01psf-b04)
[AI Thinker Tasmota Configuration documentation](https://cgomesu.com/blog/Esp32cam-tasmota-webcam-server/#installation)
[Tasmota ESP32-CAM Source Code](https://github.com/arendst/Tasmota/blob/development/tasmota/tasmota_xdrv_driver/xdrv_81_esp32_webcam.ino)

(before_installation)=
## {octicon}`sun;1em;sd-text-success`Before You Begin the Installation of a Sensor
```{warning} Before installing a sensor, make sure that the sensor you want to use is included in the Tasmota binary. This is especially important for ESP286 devices, as they have limited storage space. Verify that your sensor is included before starting the installation process.
```
Two ways to check if the sensor is in the Tasmota Build (I'd check both):
### {octicon}`sun;1em;sd-text-success`Check the Documentation
To check if a sensor is supported by Tasmota, visit [the BUILDS documentation](https://tasmota.github.io/docs/BUILDS/) and refer to the table. In the "t" column, you can find information about which sensors are included in the builds for the ESP286 and ESP32 chips. An "x" in the cell indicates that the sensor code is included in the build. For example, searching for the SCD40 sensor will show that the "t" entry has "-/x", meaning that the SCD40 sensor code is not included in the ESP286 build but is included in the ESP32 build. If you want to add support for a sensor that is not currently supported, you can follow the instructions in [the Compiling using GitPod](https://tasmota.github.io/docs/Compiling_using_GitPod/) guide.

### {octicon}`sun;1em;sd-text-success`Check from the Console
If you have installed Tasmota, you can verify if you have wired the I2C sensor correctly with the [i2cscan](i2cscan) Tasmota console command.  To check if the driver for the sensor is loaded in the Tasmota build, execute [i2cdriver](i2cdriver) from the Tasmota console.

(tasmota_installation)=
## {octicon}`sun;1em;sd-text-success`Web Install Tasmota
_Note: Web install does not work with the AI Thinker ESP32-CAM_.  To web install Tasmota, use either the Edge or Chrome web browser (the web install method does not work with Brave). Navigate to [the Tasmota Install URL](https://tasmota.github.io/install/). The first thing the Tasmota install will want to do is connect to the ESP.
### {octicon}`sun;1em;sd-text-success`Wemos D1 USB Connectivity
Connecting microcontrollers to PCs is often not as simple as "plug-and-play." If your PC is having trouble identifying the USB/COM port, try the following steps:
- Verify that the cable supports data input and output. Many USB cables are intended for power delivery only and may not support data transfer.
- Check if the CH340/CH341 driver is installed and functioning properly. The driver is essential for the PC to communicate with the microcontroller through the USB-to-serial adapter.

### {octicon}`device-camera;1em;sd-text-success`SnapBuddy USB Connectivy
The AI Thinker ESP32 does not have native USB support. We need to use an FTDI USB to Serial adapter board like the one linked [here](https://amzn.to/3CfLb5A) to translate the RS232 serial communication into a format that our computer can understand.

#### {octicon}`device-camera;1em;sd-text-success`Set Up Windows Drivers
 Assuming you are on a Windows 10 PC (I say this because it is what I am running),  follow the steps outlined in
[Darren Robinson's article, ESP32 Com Port – CP2102 USB to UART Bridge Controller](https://blog.darrenjrobinson.com/esp32-com-port-cp2102-usb-to-uart-bridge-controller/).
#### {octicon}`device-camera;1em;sd-text-success`Connect the FTDI <-> ESP32-CAM
Here's the FTDI adapter board I used.  There are many different boards available.  The setup should be the same.
:::{figure} images/ftdiSerialToUSB.jpeg
:align: center
:scale: 50

FTDI Adapter Board
:::
and
:::{figure} images/FTDI_board_pins.jpg
:align: center
:scale: 50

FTDI Adapter Board
:::

Here's how the wiring looks from the ESP32:
:::{figure} images/AIThinker-pinout.jpg
:align: center
:scale: 100

AI Thinker Cam Pinout
:::
#### {octicon}`device-camera;1em;sd-text-success`FTDI Wiring to AI Thinker Wiring

| wire color | FTDI pin | ESP32-CAM pin |
| :--- | ---: | ---: |
| yellow | RXD | U0T |
| orange or green | TXD | U0R |
| red | 5V | 5V |
| black | GND | GND |

The ESP32-CAM can be configured in two ways:

- **Flash mode**: To upload code, connect a wire between the GPIO0 and GND pins. The chip must be grounded through the GPIO0 pin to indicate that code is being uploaded.
- **Execution mode**: In this state, the GPIO0 pin is not connected to GND (i.e.: the wire can be removed).

For the next step, put the ESP32-CAM into **Flash mode**.
### {octicon}`device-camera;1em;sd-text-success` Flashing Tasmota onto the ESP32-CAM
A web install of Tasmota onto the AI Thinker ESP32-CAM kept failing.

I was far more successful installing Tasmota on the AI Thinker using [Jason2866's ESP flasher](https://github.com/Jason2866/ESP_Flasher/releases).
- Download the version for your computer (e.g.: I download ESP-Flasher-x86.exe), install locally.
- Connect the FTDI cable as well as the wire to put the ESP32 into the bootloader state.
- Follow the instructions on the UI.

AI Thinker's ESP32-CAM uses an ESP32-S chip.  There is no support for USB.  To connect the ESP32-CAM to a USB Port
AMAZING -> https://cgomesu.com/blog/Esp32cam-tasmota-webcam-server/#installation
{"NAME":"AITHINKER CAM","GPIO":[4992,1,672,1,416,5088,1,1,1,6720,736,704,1,1,5089,5090,0,5091,5184,5152,0,5120,5024,5056,0,0,0,0,4928,576,5094,5095,5092,0,0,5093],"FLAG":0,"BASE":2}

```
esptool.py --port COM5 erase_flash

esptool.exe --port COM5 write_flash -fs 1MB -fm dout 0x0 tasmota32-webcam.bin

```
https://github.com/Jason2866/ESP_Flasher/releases  - ESP Flasher - use this, put in the pics....

commands from https://cgomesu.com/blog/Esp32cam-tasmota-webcam-server/#installation

### Sensors
Install the Tasnmota Sensors binary for the ESP286 if the sensor is included by default in the Sensors build (see [before installation](before_installation)).
:::{figure} images/install_tasmota.jpg
:align: center
:scale: 100

Tasmota Web Install
:::
#### Connect to WiFi
The installation includes connecting to the home wifi.

If you want to be sure the ESP286 has been "Tasmotized" correctly, you can use a tool like [Angry IP](https://angryip.org/) to show the IP address.
:::{figure} images/angry_ip_tasmota.jpg
:align: center
:scale: 70

Angry IP Scan Shows Tasmota
:::

Choose your adventure for the rest of install:
- [Restore Configuration](restore_config) if:
  - you are building a SnifferBuddy with [the Wemos D1](https://www.aliexpress.us/item/2251832645039000.html) and the [SCD30 sensor from Adafruit](https://www.adafruit.com/product/4867).
  - you are building a [Tasmotized Plug](flash_tasmota).
- [Install Without a Configuration File](install_without_config) if you do not want to use the configuration file or a configuration file does not exist for your hardware configuration.

(restore_config)=
#### Restore Config File

Choose **Restore Configuration**

:::{figure} images/tasmota_restore.jpg
:align: center
:scale: 60

Restore Configuration UI
:::
Tasmota config files have the .dmp extension.  The backup config file is:
- `/bin/Config_snifferbuddy_11.1.0.1.dmp` for SnifferBuddy.
- `/bin/Config_mistBuddy_fan_10.1.0.dmp` for the Tasmotized plug designated for mistBuddy's fan.
- `/bin/Config_mistBuddy_mister_10.1.0.dmp` for the Tasmotized plug designated for mistBuddy's mister Power Supply.

Choose the file for the component you are building and start the restore.

(install_without_config)=
### Install Without Config File
Now Visit the Device.  Go into Configure Module and choose:
- if you are building a sensor like SnifferBuddy, choose Generic(18) and then Save.
- if you are building a Tasmotized Sonoff plug, choose
#### Configure Host Name
I like to configure the Host Name as soon as possible so I can get to the device with a name.

:::{figure} images/tasmota_wifi_snifferbuddy.jpg
:align: center
:scale: 70

SnifferBuddy Host Name
:::

Here I chose the name SnifferBuddy-SCD40 to note this is a SnifferBuddy using the SCD40 sensor.  Click on Save.  Wait for the Main Menu to come back.
#### Configure GPIO pins
Go back into Configure, and choose Configure Module.  From here set up the GPIO pins as shown in the image below.

:::{figure} images/tasmota_config_gpio_pins.jpg
:align: center
:scale: 70

Tasmota Setting GPIO pins
:::
(configure_mqtt)=
#### Configure mqtt
Go to Configure MQTT.
- Set the Host to growBuddy (assuming the mqtt broker is named growBuddy).
- Set the topic to the Buddy being enabled (in this case SnifferBuddy).
- Change the prefix part of the Full Topic to start with growBuddy.

:::{figure} images/tasmota_mqtt_config.jpg
:align: center
:scale: 70

Tasmota mqtt Settings
:::
Save and go back to the main menu.

#### Check mqtt
Using a tool like [MQTT Explorer](http://mqtt-explorer.com/)
:::{figure} images/tasmota_mqtt_explorer.jpg
:align: center
:scale: 70

MQTT Explorer
:::
We see in the image that the sensor reading for the photoresistor (A0) is available.  The value is 585.  The SCD40 values are not there.  This is because as noted in the section [Before You Begin Installation](before_installation), the SCD40 is not a part of the ESP286 sensors build.  The driver needs to be added separately as discussed above.
(tasmota_commands)=
#### Commands
Tasmota supports A LOT of [commands](https://tasmota.github.io/docs/Commands/).  The ones listed below were used on Tasmotized Buddies (like snifferBuddy).  Commands are accessed by clicking on the Console button in the main menu.
:::{figure} images/tasmota_main_screen.jpg
:align: center
:scale: 35

Tasmota main menu
:::
The main menu is then replaced with the console where commands can be entered.
:::{figure} images/tasmota_console.jpg
:align: center
:scale: 35

Tasmota main menu
:::

(set_time_between_readings)=
#### Set Time Between Readings
Set up the period between sending the sensor readings over mqtt using the `teleperiod` command.  e.g.:
```
teleperiod 60
```
sets sending readings via mqtt to occur every minute.
(set_date_time)=
#### set Local Time
This command set the correct timezone stuff for PST:

Use the web console to configure the Timezone (this shows Pacific time):
```
Backlog Timezone 99 ; TimeDST 0,2,03,1,3,-420 ; TimeSTD 0,1,11,1,2,-480
```
The 99 says to use TimeDST and TimeSTD. Use "time" to check.

[Thank you Craig's Tasmota page](https://xse.com/leres/tasmota/)

Or Keep It Simple and just change the timezone with the command `timezone -8` (see [Tasmota commands](https://tasmota.github.io/docs/Commands/#management)
#### Set Temperature Readings to F or C
Typing in the command without an option returns the current setting.
```
21:45:11.776 CMD: setoption8
21:45:11.782 MQT: growBuddy/snifferbuddy/RESULT = {"SetOption8":"ON"}
```
Weirdly, "ON" means temperature readings will be in Fahrenheit.
```
21:46:30.756 CMD: so8 0
21:46:30.761 MQT: growBuddy/snifferbuddy/RESULT = {"SetOption8":"OFF"}
```
The temperature is set to celsius with the command `so8 0`.  To Fahrenheit with the command `so8 1`.

#### Accomodate SCD30 Slow To Discover
The first time I used the SCD30 with Tasmota on a Wemos D1, it didn't work.  The reason is [discussed below](wemos_challenges).  `SetOption46` was added in Tasmota 12.1.1.  `SetOption46 0..255` stalls I2C component discovery for 0..255 * 10 milliseconds to let stabilize the local Wemos power. You might want to experiment with values like SO46 10 or SO46 20 for a 100mSec or 200mSec delay.

## Commands To Verify the Install
Two commands, `i2cscan` and `i2cdevice` are extremely helpful in determining if the software and wiring are correct.

(i2cscan)=
### i2cscan
`i2cscan` is an extremely useful command.  Executing `i2cscan` from the console is useful to **show you if the i2c sensor is wired correctly**.  It is useful right after an installation to see if the wiring to the ESP286 is correct.
```
21:41:54.158 CMD: i2cscan
21:41:54.179 MQT: growBuddy/snifferbuddy/RESULT = {"I2CScan":"Device(s) found at 0x62"}
```
The above is a verification that the wiring works for the ESP286/SCD40 I built since 0x62 is the SCD40's I2C address.
(i2cdriver)=
### i2cdriver
`i2cdriver` shows **the list of drivers that were loaded by the Tasmota build**.  For example, by default, the SCD40 is not in the ESP286 Tasmota Sensors build.  This is shown in [Tasmota's build table](https://tasmota.github.io/docs/BUILDS/).
```{image} images/scd_in_builds.jpg
:align: center
:scale: 70
```
I find the builds table challenging to read.  Here's my take:
- The rows are for each sensor where there is a Tasmota driver.
- The s column is for sensors.  I'm guessing (this is not obvious to me) the X (Sensor included) and - (Sensor not in build) in this column is referencing the **ESP286** Tasmota sensors build.
- The t column is for ESP286/ESP386 Tasmota build.  This column says the SCD30 and SCD40 are in the ESP32 Tasmota build - so I assume also in the ESP32 Sensor build since it is a subset.

```
21:40:49.852 CMD: i2cdriver
21:40:49.861 MQT: growBuddy/snifferbuddy/RESULT = {"I2CDriver":"7,8,9,10,11,12,13,14,15,17,18,20,24,29,31,36,41,42,44,46,48,62"}
```
From the results of i2cdriver, I can see the SCD40 (which sits on i2c address 0x62) is in this build.  I created a [custom build](github_compile) in order to include the SCD40 in the set of software drivers shown by `i2cdriver`.

### Switchmode
The [Tasmota command `switchmode`](https://tasmota.github.io/docs/Buttons-and-Switches/#switchmode) commands Tasmota to send an mqtt message when there is a change in state.  This command came in handy when I had an actuator that just needed on/off (like a power switch as the name implies).
```
switchmode1 15
switchmode2 15
```
(github_compile)=
### Compile Tasmota with GitPod

To add a sensor to the build or debug, you'll want to get into VS Code and play around with the code.

- This video will get you started compiling using GitPod [Compiling your own custom Tasmota on the web - No installs, no coding!](https://www.youtube.com/watch?v=vod3Woj_vrs).
- follow the directions on the [Tasmota Compiling page](https://tasmota.github.io/docs/Compile-your-build/).  Assume GitPod.
- After building, go into the build_output directory, right-click on `tasmota-sensors.bin.gz` and click to download.
:::{figure} images/tasmota_build_output.jpg
:align: center
:scale: 70

Tasmota Sensors Build Location
:::

- Go to the main Tasmota screen and select Firmware Upgrade.
- Upload the sensor binary and click on Start Upgrade.

(flash_tasmota)=
## Flash Tasmota Onto a Sonoff Plug
We need a way to turn a plug on or off.  For example, MistBuddy uses two Tasmotized plugs.  One turns MistBuddy's fan on and off.  The other turns MistBuddy's mister on and off.  By Tasmotizing the plugs, other Buddies can send mqtt messages to turn a plug on or off.

The Sonoff S31 (or S31 Lite) can be flashed so that Tasmota is running on our local network. [This YouTube video gives instructions on how to flash Tosmota](https://www.youtube.com/watch?v=9N58uy3ezvA).

ooh! Extra care when soldering.  If not, well...it is way too easy to rip off one of the pads...

Once flashed and rebooted:
- Put the plug back together.
- Set the Module type to Sonoff S31.

:::{figure} images/Tasmota_S31_Config.jpg
:align: center
:scale: 80

Tasmota Sonoff Configuration
:::
Use the Tasmota S31 configuration when you go through the [Tasmota install](tasmota_installation)

## Adding a Sensor Driver

(wemos_challenges)=
## ESP286/SCD30 Modifications

_I added this section to maintain what I learned with the Wemos D1 + SCD30 Setup_

I fixed a problem with the SCD30 + ESP286 (Wemos D1) not working without a restart.  I couldn't get the Tasmota team to look at it at the time it happened so I fixed it and submitted a PR.  A bit later on, another person had the same challenge.  Wonderfully, arendst pointed out _From the datasheet it needs 2 seconds to power up. The current code doesn't allow this._ (see [PR 15438](https://github.com/arendst/Tasmota/issues/15438)).
This may be unique to the Wemos mini D1 ESP286 (noisy power...?).

After further investigating the Wemos D1 powering and communication with the SCD 30, Arends notes: _As I thought. The Wemos D1 is flakey at power on._ (That's what $1.50 buys us!). _In latest dev there is a new command called SetOption46 0..255 allowing you to stall initialization for 0..255 * 10 milliseconds to let stabilize the local Wemos power. You might want to experiment with values like SO46 10 os SO46 20 for a 100mSec or 200mSec delay. If you own the Adafruit SCD30 you might also want to power the device from 5V as it draws a lot of power when measuring (notice the fainting power led because the wemos LDO just cannot provide enough power for the device. YMMV._

I have not had a challenge running on 3.3V.  Obviously, Arendst knows ALOT so his advice should be kept in mind.

The `SetOptions46` is avalailable in Tasmota 12.1.1

The files I modified include:
- [xsns_42_scd30.ino](https://github.com/arendst/Tasmota/blob/d157b1c5e0639f8ff29eba01fa3c181a01ae211c/tasmota/xsns_42_scd30.ino).  From what I can tell, Tasmota started as an Arduino project.  The interface into (3rd party) sensor code is a .ino file like this one for the scd30.  The current code:
```
void Scd30Detect(void)
{
  if (!I2cSetDevice(SCD30_ADDRESS)) { return; }

  scd30.begin();
```
On the ESP2866 Wemos, the code doesn't get past the initial `if` statement in the scenario when the ESP8266 is powered up.  It does pass when restarting with `restart 1` on the command line.  Most likely, powering up is taking longer on the ESP286 to the point Tasmota is impatient and doesn't wait for the scd30 to be powered up.  I did not debug further to find out how to robustly fix it.  I got to a build that "works for me" with simply:
```
void Scd30Detect(void)
{
#ifdef ESP32
  if (!I2cSetDevice(SCD30_ADDRESS)) { return; }
#endif
  scd30.begin();
```
- [tasmota/my_user_config.h](https://github.com/arendst/Tasmota/blob/d157b1c5e0639f8ff29eba01fa3c181a01ae211c/tasmota/my_user_config.h).  For more info on this file see [the Tasmota compiling YouTube video](https://www.youtube.com/watch?v=vod3Woj_vrs).  I changed:
```
#define TEMP_CONVERSION        false             // [SetOption8] Return temperature in (false = Celsius or true = Fahrenheit)
```
to `true` to show temperature readings in celsius.  As the comment states, I could have set this on the command line using [`SetOption8 1`](https://tasmota.github.io/docs/Commands/#setoptions).

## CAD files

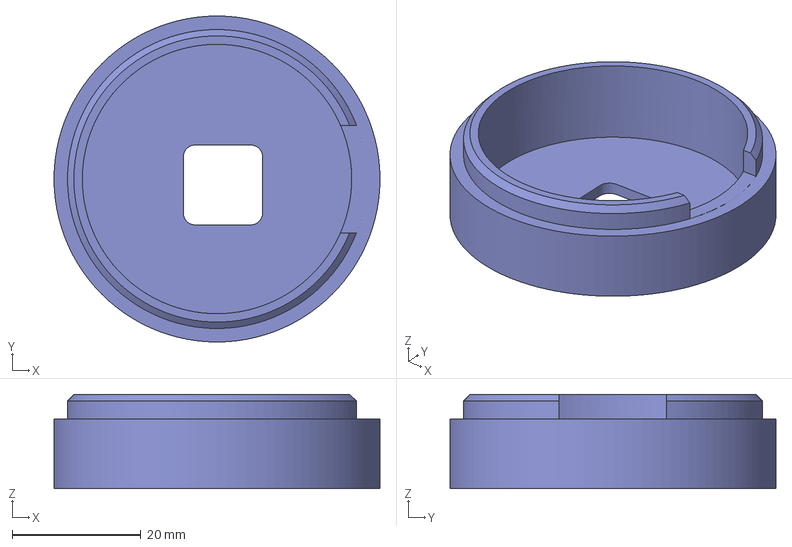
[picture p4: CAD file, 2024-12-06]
enclosure/SCD4X/scd-40 ring.3mf
50.6 x 50.6 x 14.6 mm

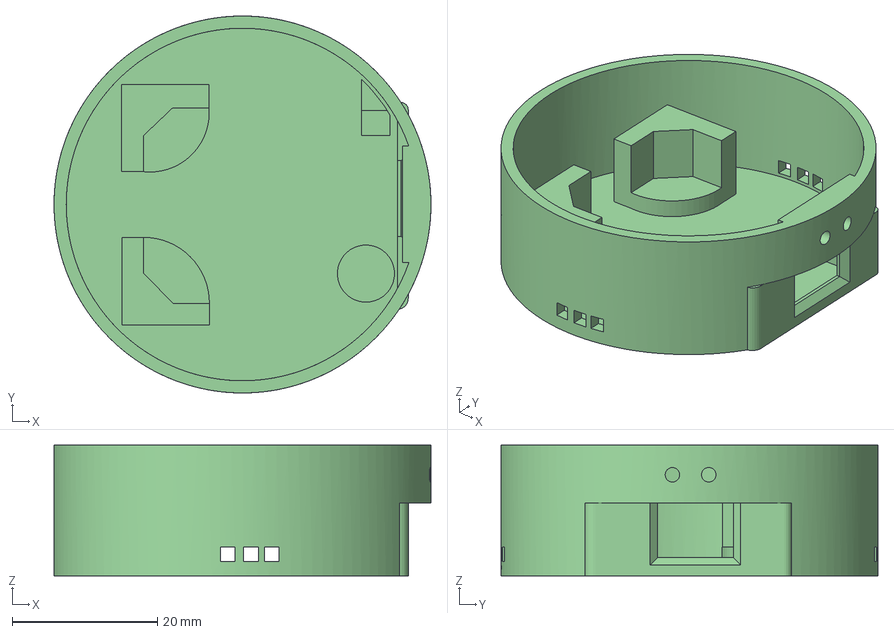
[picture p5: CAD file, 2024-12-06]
enclosure/SCD4X/wemos_bottom.3mf
51.9 x 51.9 x 18.0 mm

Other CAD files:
enclosure/SCD4X/wemos_top_v8.f3z
